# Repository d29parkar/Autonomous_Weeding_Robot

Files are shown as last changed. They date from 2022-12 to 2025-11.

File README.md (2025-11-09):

# Autonomous Weeding Robot

Weed control has been a long-standing issue in agriculture for over a century. The uniform spraying of herbicides has proved its efficiency in weed control, but it has also introduced environmental pollution, human health concerns, and herbicide resistance fears. Precision farming offers a solution to this problem by utilising weeding mechanisms to address individual plants or small weed clusters. Human-oriented precision weeding machinery, on the other hand, typically necessitates inefficient and labor-intensive human resources, which cannot justify the economic benefits of herbicide savings.

Therefore, with this project, we have presented the design, implementation and evaluation of a compact automated weed killing robot suited to traverse in marshy and moisture laden terrains, primarily cotton fields to uproot weeds which hinder growth of young cotton saplings.

The detailed report of the project is uploaded as "Project_report.pdf" in this repository.

The overall assembly of the the robot is uploaded in "CAD Models" repo as "assem1.SLDASM".

YOLO training data can be found here: [https://drive.google.com/drive/folders/1Qf1GGHQwgh6P5UD7bk6u21AzLAdbdTXJ?usp=sharing](url)
For ResNet Classification, data can be found here:
1. cotton: [https://drive.google.com/drive/folders/1kP8_Ejd9JK92aSImmd4kubfLfrTA65FS?usp=sharing](url)
2. weed: [https://drive.google.com/drive/folders/1wpcOpKExrO4X1uj2nVnzhOBSJXpHlJ4F?usp=sharing](url)

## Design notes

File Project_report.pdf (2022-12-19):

## Design & Development of Solar Assisted Autonomous Weed

## Killing Robot

## A DISSERTATION

### Submitted in partial fulfilment of the

### Requirements for the award of the degree

of

### BACHELOR OF TECHNOLOGY

in

### MECHANICAL ENGINEERING

By

Dhiraj Kiran Pimparkar (2019UME0199)

Nishtha Gupta (2019UME0180)

Shivank Kapila (2019UME0201)

Vansh Rai Saini (2019UME0200)

DEPARTMENT OF MECHANICAL ENGINEERING

INDIAN INSTITUTE OF TECHNOLOGY, JAMMU

Jagti, NH-44, Jammu - 181221, J&K, India. (Dec. 2022).

CANDIDATE’S DECLARATION

We hereby declare that the work presented in this dissertation entitled “Design & Development

of Solar Assisted Autonomous Weed Killing Robot”, submitted in partial fulfillment of the

requirements for the award of the degree of Bachelor of Technology in Mechanical Engineering

is an authentic record of work done by my/our own efforts with suitable acknowledgement to all

references.

This work has been carried out by us under the supervision of Dr. Roshan Udaram Patil,

Department of Mechanical Engineering, IIT Jammu during August 2022 to December 2022. We

have not submitted the matter embodied in this report for the award of any other degree or diploma

to any other institute or university.

Date: 10/12/2022

Place: Indian Institute of Technology Jammu

Dhiraj Kiran Pimparkar

Nishtha Gupta

Shivank Kapila

Vansh Rai Saini

CERTIFICATE

This is to certify that the above statement made by the candidate is true, to the best of our knowledge

and belief.

Dr. Roshan Udaram Patil

(Signature)

Mechanical Engineering, IIT Jammu.

## ACKNOWLEDGEMENT

We would like to express our sincere thanks, immense pleasure and gratitude to Dr. Roshan

Udaram Patil for his guidance & supervision throughout the entirety of this project. We would also

like to extend our gratitude towards the Evaluation Committee for their valuable inputs which help

shape the final product.

We are very thankful to our parents & all of our friends for their never-ending encouragement

in bringing out this dissertation report to the form as it is now.

Date : 10/12/2022

Place: Indian Institute of Technology Jammu

Dhiraj Kiran Pimparkar

Nishtha Gupta

Shivank Kapila

Vansh Rai Saini

## ABSTRACT

Research and development of autonomous mobile robotic solutions that can perform several active

agricultural tasks like sowing, harvesting, pruning etc. have been growing. Robots are now used

for a variety of tasks such as planting, weed killing, harvesting, and others. For performing these

tasks, detection of plants and weeds plays a vital role.

In this dissertation, we have developed a Solar Assisted Weed Killing Robot which is designed to

detect weeds (up to 12 cm in height) in a cotton field and remove them. Since different soils have

different water holding capacities, the design considerations for the robot have been estimated in

such a way so as to successfully traverse in marshy terrains of black cotton soil.

In the experimental section, a Raspberry Pi 4B and an Arduino Uno have been employed to garner

control of the custom 3-D printed wheels with spikes, rotor blade and an external camera for video

input feed. A Computer-Vision model using ResNet 50 architecture has been deployed on

Raspberry Pi, which is tasked with detecting and identifying if a cotton plant is present in front of

the robot or not via the video feed. The output from the computer vision model dictates the traversal

and commands the robot by prompting it to move forward, and take turns. The weed uprooting

mechanism is also characterized by the prompt received from the model to lower the rotatory blade

to perform the action of weed removal.

The present endeavor encompasses successful building of a prototype with all the mechanisms in

optimal working condition along with successful segregation of cotton and weed plants.

## CONTENTS

Certificate | 2
Acknowledgement | 3
Abstract | 4
Contents | 5
Nomenclature | 6
List of Figures | 7
List of Tables | 8

### 1 CHAPTER 1

1.1 INTRODUCTION | 9
1.2 LITERATURE REVIEW | 10
1.3 PROBLEM STATEMENT | 12
1.4 OBJECTIVES | 13

### 2 CHAPTER 2

2.1 DATASET & WORKING AREA MATRIX | 15
2.2 ROBOT MODEL & ASSEMBLY | 17
2.3 CALCULATIONS | 19
2.4 WORK STRATEGY | 21

2.4.1 Robot Path Traversal

2.4.2 Plant Identification & Detection

2.4.3 Weed Uprooting Mechanism

2.5 CIRCUIT DIAGRAMS & SPECIFICATIONS | 24

### 3 CHAPTER 3

3.1 OBSERVATIONS | 27
3.2 RESULTS AND DISCUSSION | 29

### 4 CHAPTER 4

4.1 CONCLUSIONS | 31
4.2 FUTURE SCOPE OF WORK | 33
REFERENCES | 34
APPENDIX | 35

## Nomenclature

RR | Rolling Resistance acting on the Robot
AR | Aerodynamic Resistance acting on the Robot
GR | Grade Resistance acting on the Robot
Ρ | Density of air
A | Frontal Area of the Robot
V | Velocity of the Robot
Cd | Coefficient of Drag
α | Angle of slope

## List of Figures

Chapter 1

1.2.1 Multilayer Design Framework for Intelligent Agricultural Machines & Field Robots 10

1.3.1 Line Sowed Cotton Fields | 12
1.3.2 Weeds Present in the Field | 12
1.4.1 Field Working Area in Jammu | 14

Chapter 2

2.1.1 Theoretical Grid Arrangement of Cotton | 15
2.1.2 Actual Grid Obtained in Field | 15
2.1.3 Images Captured from Field to Create Dataset | 16
2.2.1 CAD Model of Robot Assembly | 17
2.2.2 Side View of Robot Asembly | 17
2.4.1 Workflow of Path Traversal Algorithm | 21
2.4.2 Workflow of CV Model | 22
2.4.3 Workflow in Case of Weed Detection | 23
2.5.1 Hardware Connection b/w Raspberry Pi & Arduino | 24
2.5.2 Circuit for Variable Speed Control | 25
2.5.3 L298 & Arduino Powered Separately | 25
2.5.4 Hardware Connection for Linear Actuator | 26

Chapter 3

3.1.1 Output from Computer Vision Model | 27
3.1.2 3-D Printed Wheels & Robot Casing | 28
3.2.1 Wheel Assembly | 29
3.2.2 Performance of Computer Vision Model | 30

## List of Tables

Chapter 1

1.4.1 Specifications for Project Objectives | 13

Chapter 2

2.2.1 List of Components of Robot Assembly | 18
2.3.1 Design Considerations & Parametric Values Assumed | 19

Chapter 11

3.2.1 Parameters for FDM | 29

## 1.1 INTRODUCTION

Weed control has been a long-standing issue in agriculture for over a century. The uniform

spraying of herbicides has proved its efficiency in weed control, but it has also introduced

environmental pollution, human health concerns, and herbicide resistance fears. Because of the

negative consequences, governments and farmers are attempting to limit herbicide use in

agricultural activity. Precision farming offers a solution to this problem by utilising weeding

mechanisms to address individual plants or small weed clusters. Human-oriented precision

weeding machinery, on the other hand, typically necessitates inefficient and labor-intensive human

resources, which cannot justify the economic benefits of herbicide savings.

Because of its considerable potential to improve weeding efficiency while lowering environmental

and economic costs, automated weed control, including weed detection and removal, has acquired

substantial popularity in the precision farming community in recent years. Many robotic weed

control systems have been proposed, with a focus on single tactics such as selective chemical

spraying, mechanical weeding, flaming, and electrical discharge. To detect weeds, smart weeding

machines rely on the performance of the machine vision system. However, environmental

uncertainties such as illumination and colour variation in leaves or soil impair the performance of

the machine vision system, limiting the weed control accuracy. Significant progress has been made

toward learning-based weed detection technologies as artificial intelligence has flourished. Such

systems, which employ a Convolutional Neural Network (CNN), have been shown to produce

more reliable crop/weed detection findings.

Within the scope of our project, we have presented the design, implementation and evaluation of

a compact automated weed killing robot suited to traverse in marshy and moisture laden terrains,

primarily cotton fields to uproot weeds which hinder growth of young cotton saplings. Cotton was

chosen as part of the study as it constitutes a majority chunk of the agricultural economy and as of

now, is extremely expensive due its labour-intensive nature of weed uprooting in thick black soil.

By targeting this niche and automating it, we aim to innovate a sustainable solution for cotton

farming industry.

## 1.2 LITERATURE REVIEW

After conducting a detailed literature survey to understand the developmentds made in this domain

we came across a multilayer design framework for intelligent machines and field robots consisting

of four technology layers. This can be depicted in Figure 1.2.1. They tend to stack on each other

beginning from the machine architecture layer containing both the hardware and software

architecture required for the robot’s functioning. Next comes the machine awareness layer

consisting of the perception localization, and monitoring technology required by the robot to be

aware of its own systems and environment.

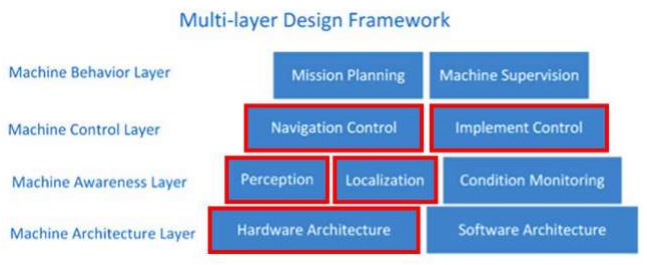
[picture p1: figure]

Figure 1.2.1: Multilayer design framework for intelligent agricultural machines & field robots

Robots interact with their surroundings, necessitating the inclusion of actuator control systems in

the machine control layer. Machine planning and supervision technologies connected with the top

machine behaviour layer are essential for autonomy and the ability to achieve goals under

uncertainty. According to a review of the literature, robotic weeder technologies have typically

included technology at the lower three layers such as hardware architecture, perception,

localization and navigation, and implement control. The machine behaviour layer, as well as

condition monitoring technology, are mainly lacking. As a result, it is impossible to conclude,

without diminishing the technological effort published in the literature, that we have robotic

weeding technology today. However, developments in the field are accelerating.

All the robotic weeders documented in the literature are not truly robotic weeders, but are

‘essentially self-guiding vehicles carrying weeding tools.’ It is based on the fact that the practical

application of mechanical weeding instruments is complicated. This complexity is due to various

aspects, including soil qualities that change depending on soil type and environmental conditions

such as soil moisture content, variability in weed plants and crop plants, and the reaction of these

plants to mechanical weeding instruments.

Several key factors must be met for agricultural robots to effectively control weeds. Problems must

be resolved. First, weed and crop plants need to be accurately spotted in a field of crops. Plant

location, classification of weed and crop plants, and plant detection must all be part of the

perceptual system. Second, the weed control strategies that best suit the cultural norms of the

production system must be considered while developing the weed control mechanisms. Third, the

mechanism must be directed to function near the locations of the weed plants and far from the crop

plants depending on the data from the perception system. Fourth, a weeding system must

incorporate each of these technologies. We focused on developing of a robotic weeder including a

perception system and path traversal algortihm specifically targeted around cotton plants. The

adaptability of the system still stands with the flexibility factor primarily dependent upon the

dataset proivded for training and validation purposes. However, the design is precisely designed

to operate in fields where line-sowing is a common practice.

## 1.3 PROBLEM STATEMENT

The Indian economy is largely agro-based as agriculture constitutes the backbone of the rural

livelihood security system. With more than 100 million farm holdings, agriculture supports more

than 60 % of the total population in India and contributes about 19% to India’s GDP. With cotton

at the forefront, it contributes about 16% of the total agricultural-crop of the country with India

possessing the largest area under cotton cultivation which is nearly 9 million hectares. Therefore,

it becomes increasingly crucial to ensure a good annual harvest as it holds a significant chunk in

the exports in the Indian economy. Each year, massive capital investments are required in terms

of manpower as extensive care is required by the line sowed cotton plants during their early

development stages. Any obstruction such as weeds can significantly affect and hinder their

growth. Additionally, while operating here, the moisture retentive black soil poses difficulty to

work in due to its extremely marshy nature. This makes the task of weeding very difficult and

labour intensive. Hence, it becomes necessary to incorporate automation in this sector and provide

a sustainable solution to address this grave issue and ensure good yield of cotton plants by

uprooting weeds in a more economical fashion. Refer Figure 3.1 & 3.2 for cotton fields and weed

presence in fields.

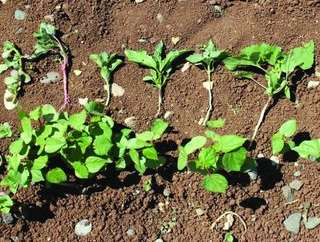
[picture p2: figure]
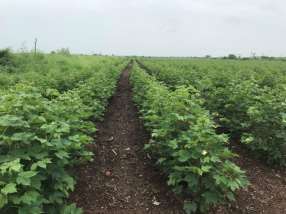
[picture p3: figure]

Figure 1.3.1: Line Sowed Cotton Fields | Figure 1.3.2: Weeds Present in the Field

## 1.4 OBJECTIVES

- Designing & developing a robot capable of traversing in marshy terrains.
- Developing a computer vision model to facilitate cotton plant identification.
- Developing a path planning and mapping algorithm for autonomous maneuvering of

the robot in alien terrains.

- Developing a weed uprooting mechanism to uproot weeds up to 12 cm in height.

The primary objective of this project is to develop a solar power assisted autonomous weed killing

robot. The robot specifications should be such that it can traverse in marshy black soil while

avoiding sinkage and move freely amongst the cotton grids. The agenda of developing this robot

caters to uprooting weed around young cotton plants to prevent hampering their growth. The

problem scope and objectives that are dealt with as part of this research project are as follows in

Table 1.4.1:

Problem Scope to be Dealt With | Specification
Field Size (Working Area) | 25 x 30 sq. ft
Soil Density | 1.81 - 2.08 g/cm^3
Operation Time | 30-35 mins
Weight | Under 10 Kgs
Operational Stage | Budding cotton plants (H= 2-3 ft)
Grid Size for Each Plant | 20 cm x 20 cm

Table 1.4.1: Specifications for Project Objectives

For the purpose of this project a field was planted with cotton seeds to serve as our working area

and facilitate manual curation of dataset to suit our requirements. Refer to Figure 1.4.1 for the field

working area in Jammu.

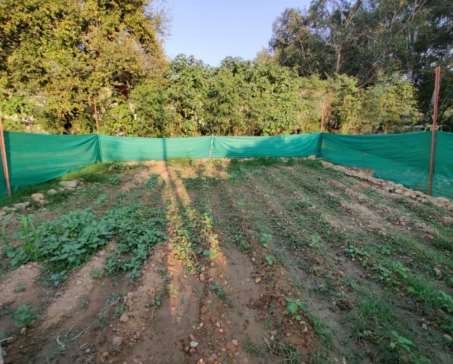
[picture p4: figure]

Figure 1.4.1: Field Working Area in Jammu

## 2.1 DATASET & WORKING AREA MATRIX

Cultivating our own cotton field sowed in matrices was crucial for the development of the project

to procure data and understand the practical obstructions the robot might face while maneuvering

autonomously. It yielded reliable data spread across weeks to record all stages of plant growth for

long-term considerations. Figure 2.1.1 & 2.1.2 demonstrate the theoretical and actual grid size and

matrix obtained with line sowed cotton.

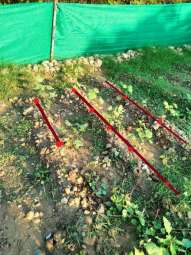
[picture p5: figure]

Figure 2.1.1: Theoretical Grid Arrangement of Cotton | Figure 2.1.2: Actual Grid Obtained in Field

To suit the requirements of our robot and train it precisely instead of availing the dataset available

on the internet, we manually curated our own dataset and video footage to handle real-life

situations in a more concrete way and make our model robust. While procuring the images,

extensive care was given to collect the photographs at a specified height and angle of 18 inches

and 30 degrees from the vertical respectively. This was ensured in order to accurately replicate the

point of view of the camera module on the robot and hence obtain better results. Some images can

be seen in Figure 2.1.3 which demonstrate the various situations our robot might encounter itself in: plain terrain, rocky terrain, marshy terrain and area with a thick growth of weed. To access the

full dataset, refer to the appendix.

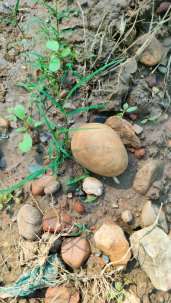
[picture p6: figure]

Fig. 2.1.3.1 | Fig. 2.1.3.2

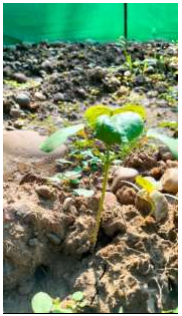
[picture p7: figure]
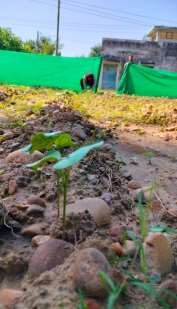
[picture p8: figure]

Fig 2.1.3.3 | Fig. 1.5.3.4

Figure 2.1.3: Images Captured from Field to Create Dataset

## 2.2 ROBOT MODEL & ASSEMBLY

With the specifications laid out the designing considerations were obtained to aid in the

development of the CAD model of the robot. Refer to Figure 2.2.1 & 2.2.2 for the assembly.

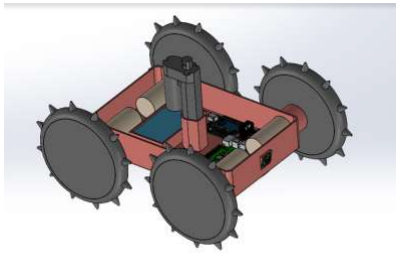
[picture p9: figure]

Figure 2.2.1: CAD Model of Robot Assembly

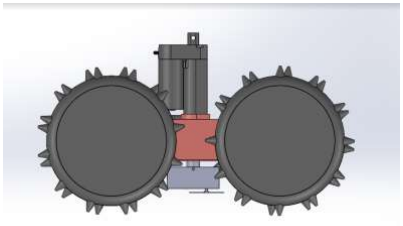
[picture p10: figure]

Figure 2.2.2: Side View of Robot Assembly

The list of components incorporated in this assembly are as follows as found in Table 2.2.1:

Component | Quantity
Wheels | 4
Actuator Stroke | 1
Linear Actuator | 1
Arduino Uno | 1
Battery | 1
Fan Blade | 1
Body Casing | 1
Raspberry Pi 4B with Camera Module | 1
Connector Rod | 1
Motors | 5

Table 2.2.1: List of Components in Robot Assembly

Refer to the appendix for the drawings of all the components in the assembly.

## 2.3 CALCULATIONS

The assumptions and design considerations taken into account while performing the calculations

have been listed below in Table 2.3.1

Design Consideration | Value
Weight of the Robot | 100 N
Wheel Radius | 0.08 m
Efficiency of Transmission (%) | 90
Coefficient of Friction | 0.65
Coefficient of Rolling Resistance | 0.15
Target Gradability (%) | 50
Target Velocity (m/min) | 10
Frontal Area of Robot (m² ) | 0.02
Density of air (kg/m³ ) | 1.225

Table 2.3.1: Design Considerations & Parametric Values Assumed

For deciding the required specifications of the motor, we’ll estimate all the loads acting on the

robot.

Total LoadRobot = RR + AR + GR

RR estimation:

RRRobot = μ * WeightRobot

RRRobot = 0.15 * 100 = 15 N

AR estimation:
ARRobot = ½ *ρ*A*V²
*Cd
ARRobot = ½ * 1.225 * 0.02 * (10/60)² * 1

ARRobot = 0.003 N

GR Estimation:

GRRobot = Weight * sin(α)

GRRobot = 100 * sin (26.56°) = 44.72 N

Total LoadRobot = RRRobot + ARRobot + GRRobot

= 15 + 44.72

= 59.72 N

Torque Required on Wheels (Tw) = Total LoadRobot * RadiusWheel

= 59.72 * 0.08

= 4.77 N-m

Torque to be Supplied by Motor (TM) = TW/ (Efficiency*Gear Ratio)

= 4.77/ (0.9*1)

= 5.3 N-m

Torque Supply per Motor = TM/Number of Motors

= 5.3 / 4

= 1.325 N-m

## 2.4 WORK STRATEGY

### 2.4.1 Robot Path Traversal

The robot path traversal algorithm traces out & maps the path to be travelled by the robot. The

algorithm deployed for the same is A* search algorithm which is a graph traversal and path search

algorithm. The heuristics incorporated here define how the robot

Heuristic = w (Manhattan Dis. to Goal State) + (1-w) ( Perpendicular Dis. to S1-G1 Line)

The flowchart for the working of the path traversal algorithm can be seen in Figure 2.4.1

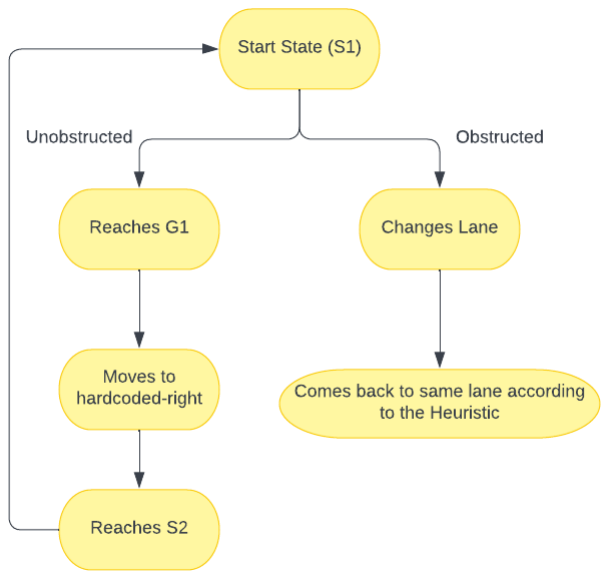
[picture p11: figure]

Figure 2.4.1: Working of Path Traversal Algorithm

### 2.4.2 Plant Identification & Detection

The computer vision model employs ResNet architecture as its image processing algorithm. The

external camera module which dangles in the absolute front of the robot vehicle has been placed

in such a way so as to avoid any overlooking of weeds. The camera module captures and inputs

video feed to the computer vision model at an interval of 10 frames for processing and the output

identifies and labels the plant as ‘Cotton’ or ‘Not Cotton’. Thus, if a weed is identified the response

for triggering the weed uprooting mechanism is set into motion. Figure 2.4.2 displays the

algorithmic flowchart of how it operates.

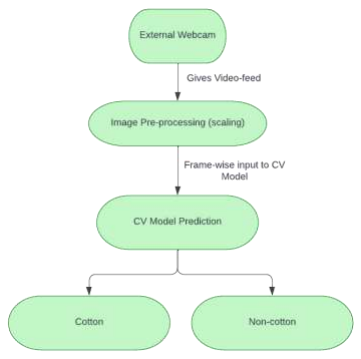
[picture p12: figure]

Figure 2.4.2: Workflow of CV Model

### 2.4.3 Weed Uprooting Mechanism

The weed uprooting mechanism that has been integrated with the system includes a motor blade

which is lowered via a linear actuator of maximum stroke length of 100 mm. In case the computer

vision model detects any weed, the robot is immediately brought to rest and the mechanism is set

into motion. The Raspberry Pi relays the signal to L298 via Arduino Uno while simultaneously

triggering the linear actuator. The pictographic representation has been depicted in Figure 2.4.3

which can be found below.

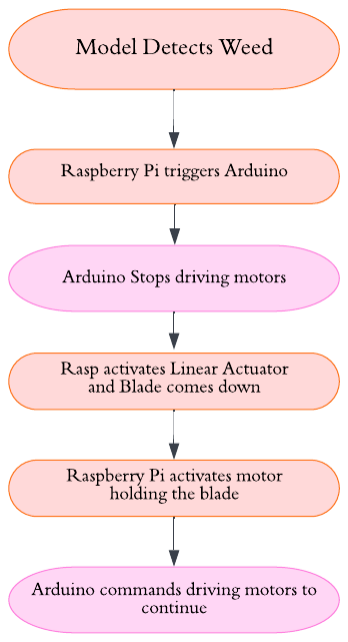
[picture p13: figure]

Figure 2.4.3: Workflow in Case of Weed Detection

## 2.5 CIRCUIT DIAGRAMS & SPECIFICATIONS

The circuit diagrams are crucial in representing the essence of the working of the robot. Various

mechanisms operate in unison to optimally function the robot in its task of uprooting weeds while

deployed in the working area. Three primary circuits have been integrated to perform and set

communication which include:

Raspberry Pi – Arduino Uno Communication

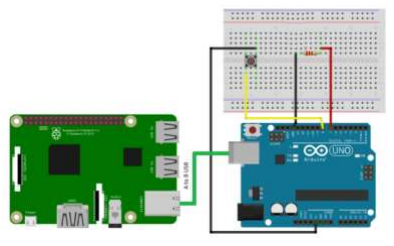
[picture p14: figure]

Figure 2.5.1: Hardware Connection b/w Raspberry Pi & Arduino

Figure 2.5.1 depicts the hardware connection between Raspberry Pi & Arduino Uno. It has an

added camera module which provides the input to the processing unit and is evaluated by the

Computer Vision Model. The command is further relayed via Arduino to perform the necessary

action. The specifications of the components are listed below:

- Raspberry Pi 4 Model B; 4 GB, ARM-Cortex-A72 4 x, 1.50 GHz, 4 GB RAM, WLAN-ac,

Bluetooth 5, LAN, 4 x USB, 2 x Micro-HDMI

- Breadboard with 400 Tie Points (BB-801)
- Arduino Uno R3 ATmega328P with USB Cable

Arduino Uno – Motor Driver – Motor Communication

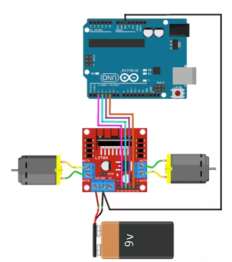
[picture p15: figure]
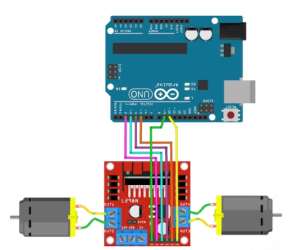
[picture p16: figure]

Figure 2.5.2: Circuit for Variable Speed Control Figure 2.5.3: L298 & Arduino Powered Separately

Figure 2.5.2 & 2.5.3 denote the hardware connection for variable speed control of motors and the

power supply of the circuit respectively. The Raspberry Pi relays commands to the Arduino to

control the motors and the robot and a power supply of 12V is being provided. The specifications

of the components are as follows:

- Orange Planetary Gear DC Motor 12V 92RPM 234.7 N-cm PGM45775-50.9K
- Motor Driver L298 dual H-bridge driver chip.
- Panasonic Li-Ion 2000mAh type, 1900mAh min, pre-charged rechargeable AA batteries.
- 8 CELL 1.5v AA Battery Case Holder, Battery Holder Box with Cover ON/Off Switch

Arduino Uno – 2 Channel Relay – Linear Actuator Communication

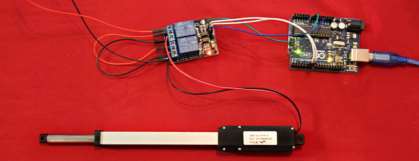
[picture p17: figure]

Figure 2.5.4: Hardware Connection for Linear Actuator

Figure 2.5.4 represents the hardware connection between the processing unit, to a 2-channel relay

which further activates the linear actuator. This connection is triggered by the computer vision

model when it detects any nearby weed. The linear actuator gently lowers the piston to

consequently lower the blade for any removal of weeds detected. The specifications of the

components used for this circuit include:

- Linear Actuator Stroke Length 100MM,7mm/S,1500N,12V
- 5V 10A 2 Channel Relay Module Shield for Arduino ARM PIC AVR DSP Electronic

## 3.1 OBSERVATIONS

When the robot was deployed in the field it was observed that with the non-conventional wheel

designs that have been used in the robot with the spikes, we were able to successfully maneuver

in the marshy terrain. The robot did not wobble much and remain stabilized while traversing. The

rocky terrain was within the scope of expectations leading to enhance the motor design

considerations. However, the speed output expected was slightly lower relative to the theoretical

value.

When the camera was tested in the field to ensure high performance of the computer vision model,

the following results were obtained as seen in Figure 3.1.1:

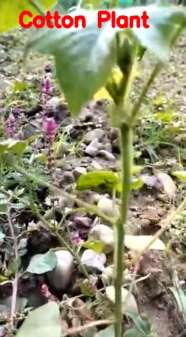
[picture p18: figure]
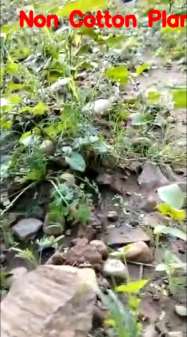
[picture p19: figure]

Figure 3.1.1: Output from Computer Vision Model

The traversal of the robot from the start state to the goal state with continuous updating for each

grid was successful with the robot completing this distance without waving off its path. Therefore,

it was observed that integration of A* search algorithm for path planning was a success.

For removal of weed the mechanism in place we aim to be able to cut it down to its stem, with the

remains still present near the main plant body. It was safe to conclude that the robot is capable of

doing this task while testing the circuit of linear actuator separately from the body.

As for the components, the 3D printed parts include customized wheels and the robot body as

observed in Figure 3.1.2. The printed casing was observed to be a little deviated from the CAD

model due to some errors in the FDM 3-D printer.

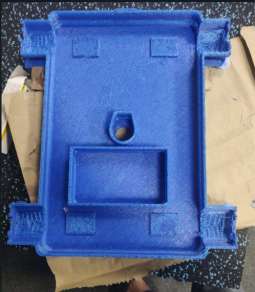
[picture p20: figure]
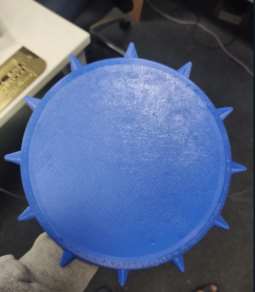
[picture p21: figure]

Figure 3.1.2: 3-D Printed Wheels and Robot Casing

## 3.2 RESULTS & DISCUSSION

The wheel was successfully manufactured using the FDM 3D printer available in the tinkering

lab. The material was chosen to be Polylactic Acid. Table 3.2.1 shows the parameters for 3-D

printing.

Table 3.2.1: Parameters for FDM

S. No. | Parameter | Value
1 | Infill Density | 20%
2 | Infill pattern | Triangle
3 | Printing Temperature | 210 ℃
4 | Build Plate Temperature | 60 ℃
5 | Printing Speed | 50 mm/s
6 | Top Thickness | 0.3 mm
7 | Bottom Thickness | 0.6 mm

The base was not successfully printed due to some technical problem in the nozzle. The parameters

were chosen to be the same as that of the wheel. We observed an abundance of pores in the base

which significantly reduced its strength.

Figure 3.2.1: Wheel Assembly

Figure 3.2.1 shows the wheel assembly. The keyway was purposely designed to be of a tight fit to

prevent slipping. This resulted in a great torque transfer from the motor to the wheels.

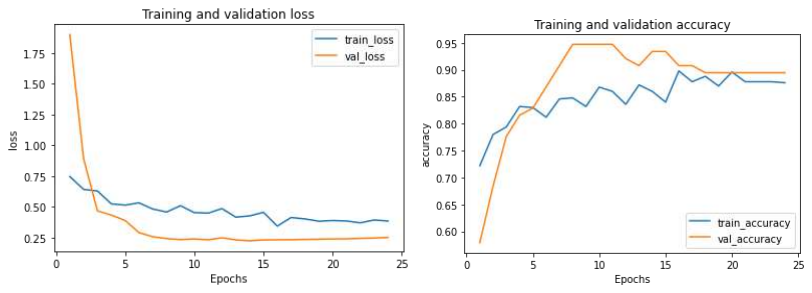
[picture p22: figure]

Figure 3.2.2: Performance of Computer Vision Model

Using the site-collected dataset, we trained a computer vision model to recognise cotton plants. Its

accuracy in both training and validation was 90.1% and 89%, respectively. The plot shown above

in Figure 3.2.2 displays how the accuracy and loss vary with training epochs. We can observe that,

while converging without overfitting, our validation loss is less than our training loss. Furthermore,

it is implied by the plot, it is neither exploding or becoming stranded.

## 4.1 CONCLUSION

This work proposed the development of a weed uprooting robot with current state-of-the-art

localization and mapping techniques along with a well-equipped computer vision model to identify

and differentiate between cotton and weed. After an intensive research and development phase

spanning over 12 weeks we were able to develop a working prototype characterized and trained

by the dataset which was manually curated to specifically suit the needs of the robot. The scope of

this project focuses on the early developmental stages of young cotton plants with a height of about

25 inches. After developing a deeper product sense, segregating the current targets from future

goals was facilitated with the research to enhance the prototype extending to the next semester.

Since there were about four major considerations in this robot the following could be mapped out

for the domains:

Robot Design:

The robot body was deliberately made small for efficient maneuvering in between the narrow

channels. With proportionately larger wheels attached at a small angle, a degree of stability was

imparted to the model to avoid any toppling. A protruding camera in front of the robot relays the

visual input to Raspberry Pi model so that the robot does not miss or cross any potential weeds

along the way.

Cotton Identification Model:

It is safe to conclude that by employing the ResNet Architecture with a dataset of over 800 images,

an accuracy of 89% was achieved. The computer vision model was successful in identifying the

plants even in a destabilized self-captured video input. Further enhancements in the model have a

direct positive correlation with the increasing number of epochs and quality data.

Traversal & Path Planning Algorithm:

The A* traversal algorithm employed in the robot includes simple linear motion with a restricted

degree of freedom of movement to avoid wandering away from the established grid structure.

When it reaches the end of a channel, it takes a 90 + 90 degree turn towards the right following

the channel yet again. The requirement of 3D localization in agriculture is quite rare with research

still premature. The integration of localization & mapping algorithm with the model is still

underway with a tremendous potential to grow.

Weed Uprooting Mechanism:

The current weed uprooting mechanism employs a rotatory blade and a linear actuator which is

gradually lowered in case of presence of weed. The output from the motor is successfully converted

by the actuator and the blade cuts down the weed from surface level. A deeper uprooting of weed

takes place in soil areas with a soft texture which can be penetrated by the blade with ease and

without suffering any damage.

## 4.2 FUTURE SCOPE OF WORK

The autonomous weed killing robot developed yielded exciting results but also revealed pathways

for improvement and future scope of work. Some problems that were faced during the fabrication

phase of the robot need further diving into for either enhancement or troubleshooting. There

remains much scope to improve the accuracy of the computer vision model by deploying latest

algorithms and harboring access to ‘Agastya’ supercomputer to accelerate model training and

validation.

Implementation of path planning and traversal algorithms for localization and mapping of alien

territories requires expertise in SLAM, an algorithm which is still premature in context to

agriculture and forestry. By modifying the design of the model to accommodate more cameras, we

may be able to reduce the engagement of a single camera for multiple visual tasks. By enhancing

the power supply and establishing a solar-powered recharging station to ensure constant power

availability we may procure video feeds from multiple perspectives for training an end-to-end

model for weed-crop identification and detection. Regular monitoring by the robot and relaying

the feed to a database, a library of weed and cotton plant images can be curated to bolster the

research of crop-weed differentiation.

References

1. Wu, Xiaolong & Aravecchia, Stéphanie & Lottes, Philipp & Stachniss, Cyrill & Pradalier,

Cedric. (2020). Robotic weed control using automated weed and crop classification.

Journal of Field Robotics. 37. 10.1002/rob.21938.

2. Averill, K.M. et al. (2022) “Effects of Tertill® weeding robot on weed abundance and
diversity,” | Agronomy, | 12(8), | p. | 1754. | Available | at:

https://doi.org/10.3390/agronomy12081754.

3. Du, Y. et al. (2021) “A low-cost robot with autonomous recharge and navigation for weed

control in fields with narrow row spacing,” 2021 IEEE/RSJ International Conference on

Intelligent | Robots | and | Systems | (IROS) | [Preprint]. | Available | at:

https://doi.org/10.1109/iros51168.2021.9636267.

4. Steward, B., Gai, J. and Tang, L. (2019) “The use of agricultural robots in Weed

Management and Control,” Robotics and automation for improving agriculture, pp. 161–

186. Available at: https://doi.org/10.19103/as.2019.0056.13.

Appendix

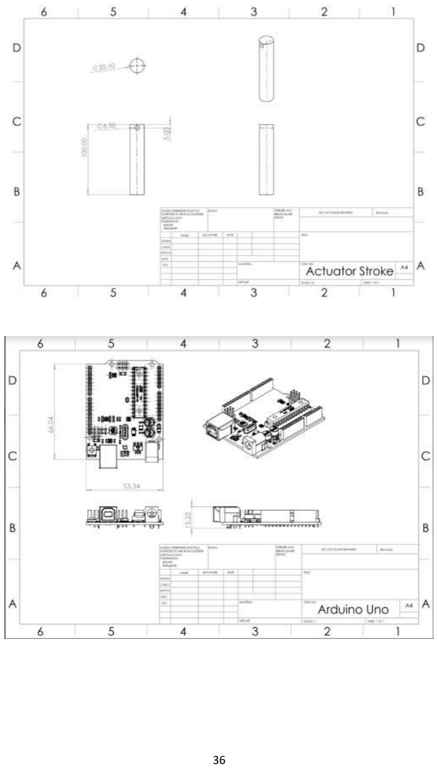
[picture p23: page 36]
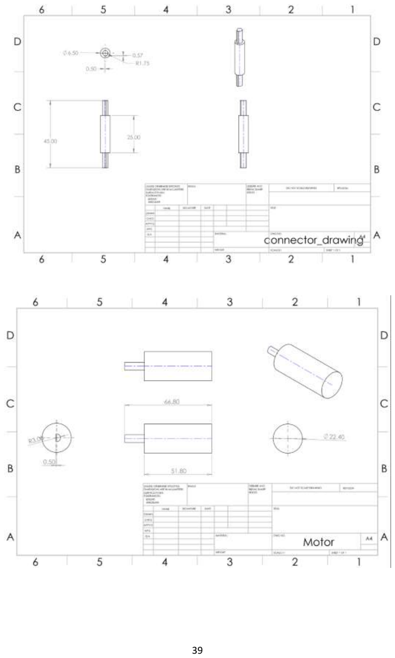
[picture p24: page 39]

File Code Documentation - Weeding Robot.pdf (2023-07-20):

After setting up the raspberry pi and setting up the ssh, follow the below-mentioned steps to run code for multiple tasks:

### 1. Motor with speed control:

File - motor_with_speed_control.py
All the motor and linear actuator-related tasks can be accomplished using this file. Verify that all the Raspberry Pi GPIO pins are connected to their respective motors and linear actuator.
You can use the following diagram as a reference:


The GPIO pin numbers will depend upon what GPIO.setmode(GPIO.BOARD) or GPIO.setmode(GPIO.BCM), as seen in the following image.
[In the image as well as by default in the code file: GPIO.BOARD mode is set]


Eight tasks can be accomplished using this Python file -
a. Forward
b. Reverse
c. Left_turn
d. Right_turn
e. Cutting
f. Stop_cutting
g. Actuate
h. Dactuate

We can progressively mention the task we want to accomplish in the while loop of the file, as can be seen in the image below:


Note:
You have to mention the time.sleep(x) [x being the number of seconds] after every task, as seen in the image.
Speed can be mentioned from range (0, 100), though, for speeds < 15, the robot might not move due to its inability to overcome static friction.

### 2. For all the tasks:

File: BTP_main.py [GitHub], BTP folder, file name: main.py (or similar) [Raspberry Pi memory card]

This file contains the entire code for the weeding operation apart from the path traversal. The code initially captures the webcam video with cv2.VideoCapture(0) command.

The object detection model identifies the weed and cotton plants based on their training and operates accordingly.

If the weed is found to be with > 0.5 confidence, the robot will start its cutting operation.
No code is written for the cotton plant to replan the robot's path based on its identification.

### 3. Computer Vision Model Scripts - Resnet:

File: CV_model.ipynb [Github] - very well-organized and easy-to-use Python notebook This file contains the entire code required for computer vision model training.
The file also contains code for testing the model on any video or webcam input based on the cv2.VideoCapture(0) command.
The data on which it is trained is attached with the google drive link below.

### 4. Object Detection Scripts - YOLOv7:

File: yolo_training.ipynb [Github]
This file contains the entire code required for YOLO model training.
The code for model testing is also mentioned in the Python notebook.

### 5. Path Traversal Scripts - A-star:

File: Astar_weed_killing_robot.ipynb
All the heuristics and conditions have already been implemented for the path traversal. [For more info about the heuristics, you can refer the BTP report file]
The only input required for the operation of the code is start_node and end_node. Call the run function from the initialized Robot class, giving it all the arguments.
The image displays the entire path that the algorithm has designed.


The object detection and path traversal files haven't been integrated fully into the motor operation codes, which can be a task of future developers. However, it has been attempted in a few files found in the raspberry pi memory card but hasn’t been tested.

For any information, contact: Vansh Rai Saini: +91 96544 58060 Dhiraj Pimparkar: +91 98501 92860 Nishtha Gupta: +91 94525 01659 Shivank Kapila: +91 97977 11244

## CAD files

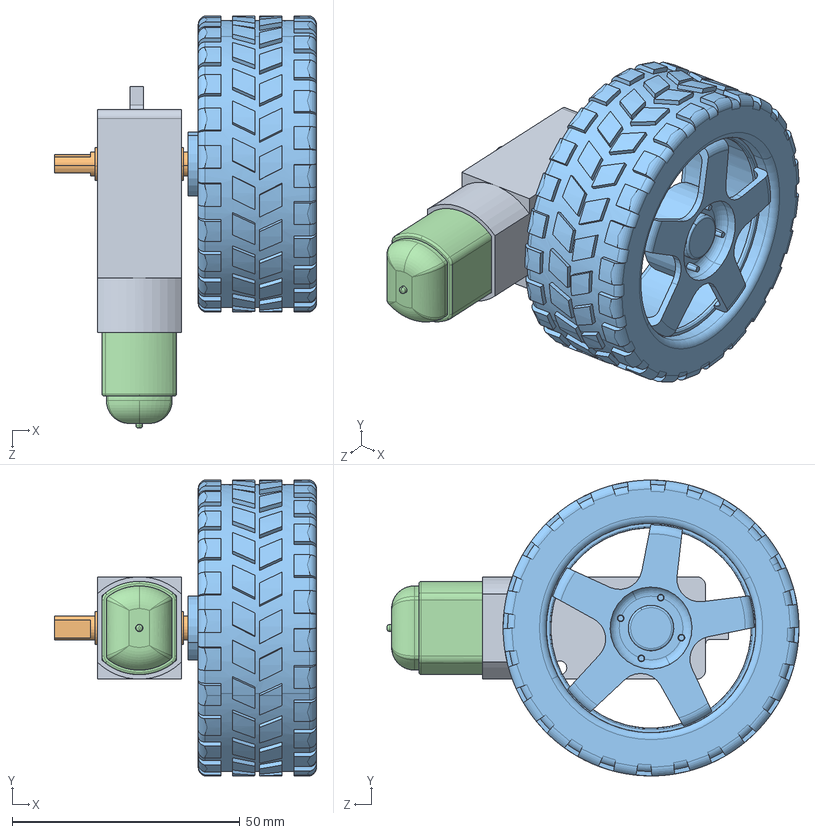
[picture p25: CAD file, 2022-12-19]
CAD Models/Bo Motor With Wheel.SLDASM
57.6 x 65.0 x 90.5 mm
Real Bo Motor Gear Box.STEP
Shaft.STEP
Real Wheel.STEP
Real Bo Motor Frame.STEP

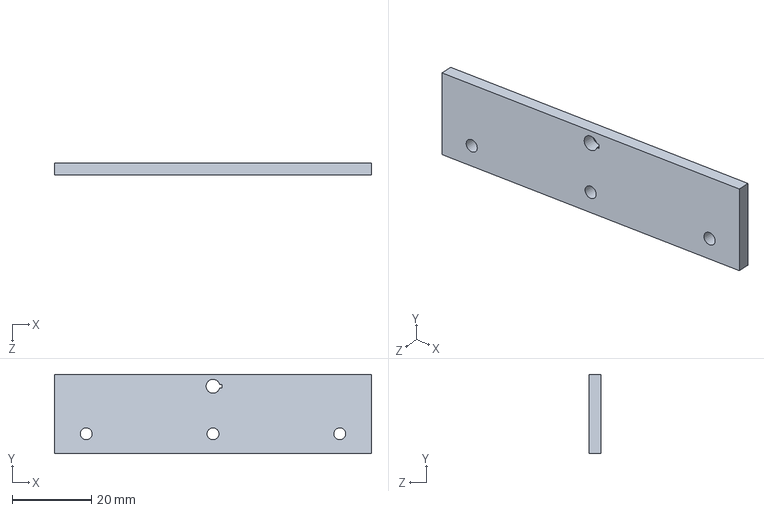
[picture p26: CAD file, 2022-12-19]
CAD Models/assembley component.SLDPRT
80.0 x 20.0 x 3.00 mm

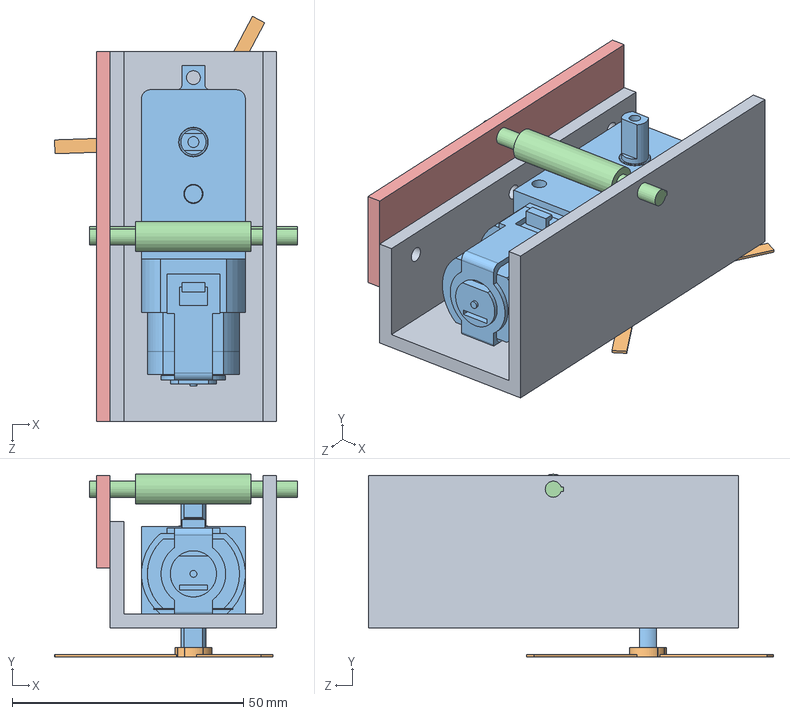
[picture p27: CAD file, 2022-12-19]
CAD Models/tool_assembly.SLDASM
52.5 x 39.5 x 87.7 mm
tool_casing
blade
BO DC Motor
connector
assembley component

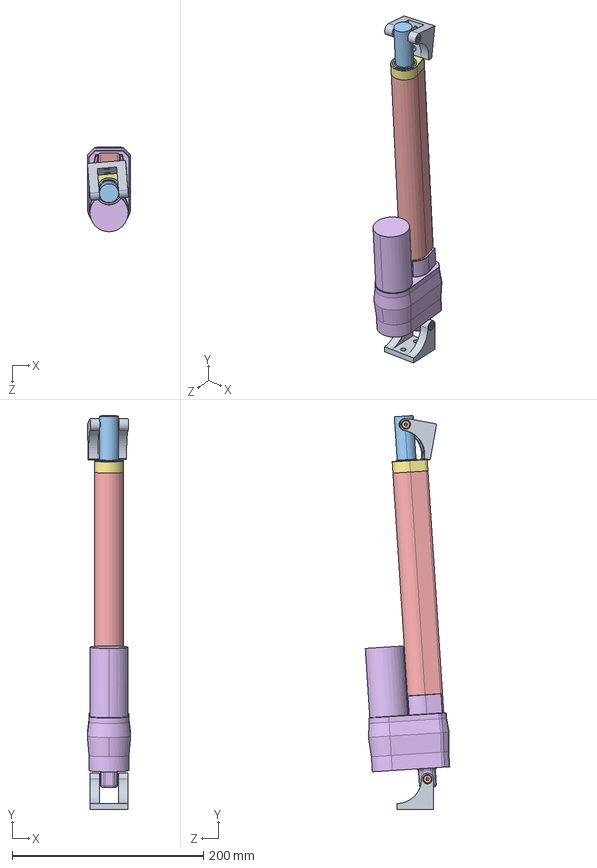
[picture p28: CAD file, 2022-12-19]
CAD Models/linear actuator.SLDASM
45.5 x 412.5 x 88.5 mm
HDA Clevis Mount.STEP x 2
Shoulder Bolt .25 x 1 - 10-24_SHSSCREW 0.25x1-N.STEP x 2
HDA-STROKE_8IN.STEP
HDA-CAP-SEAL.STEP
HDA-SHROUD_8IN.STEP
HDA-BASE.STEP
HDA-SHROUD-CAP.STEP

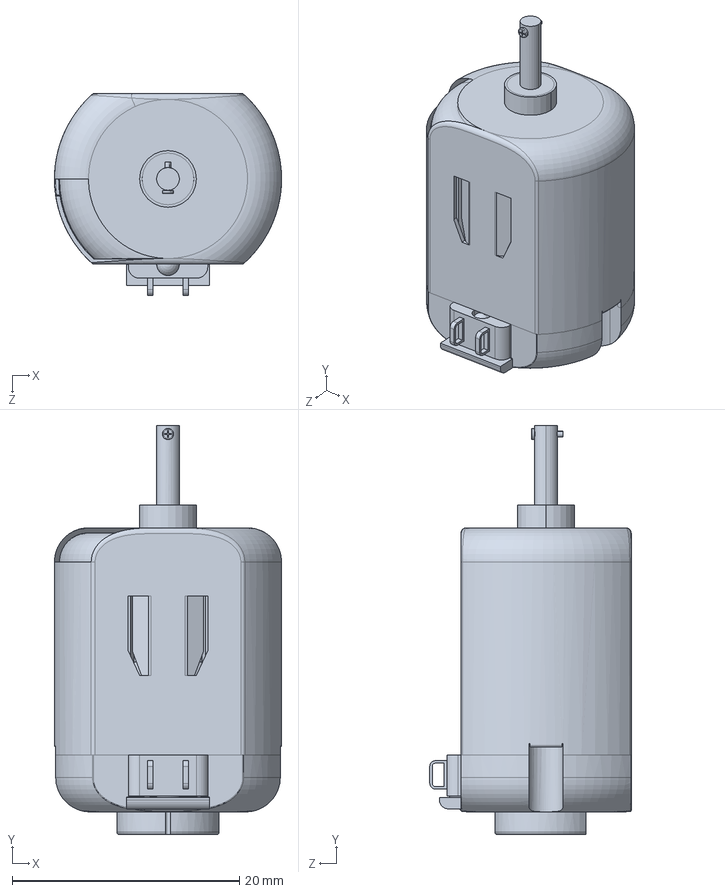
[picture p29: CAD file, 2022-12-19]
CAD Models/DC_Motor assembly.SLDPRT
20.0 x 36.0 x 17.7 mm

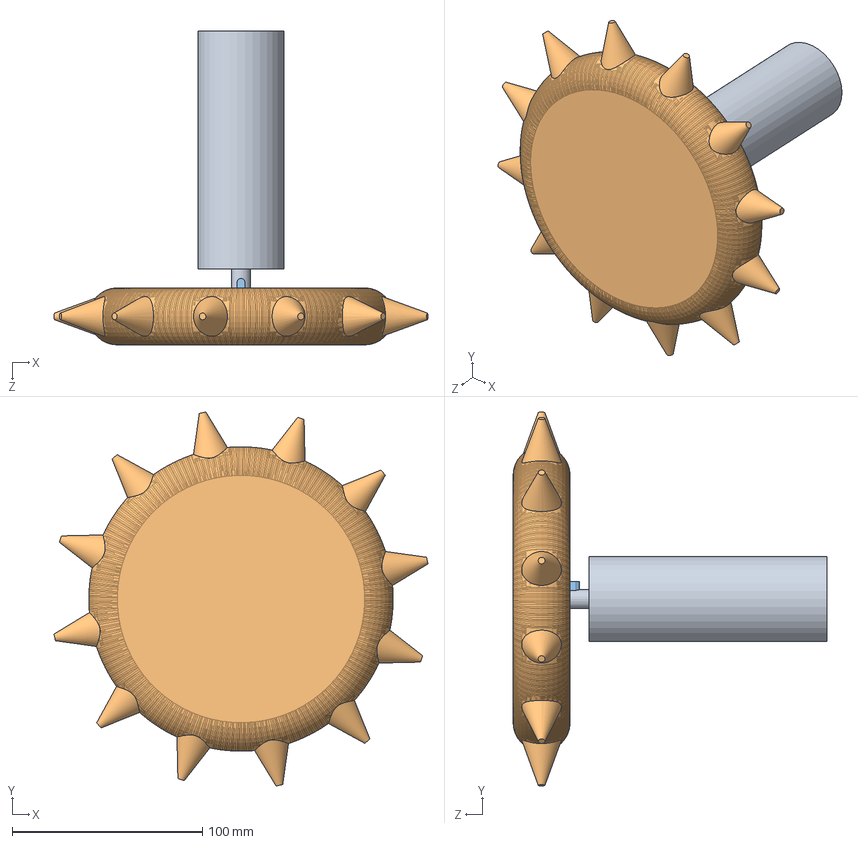
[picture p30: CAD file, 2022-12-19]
CAD Models/motor_wheel_sub_assemb.SLDASM
196.6 x 196.6 x 165.0 mm
motorV2
WheelV2
key

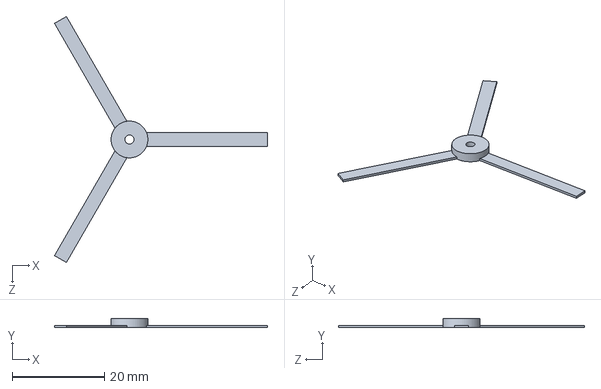
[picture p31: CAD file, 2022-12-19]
CAD Models/blade.SLDPRT
46.3 x 2.00 x 53.5 mm

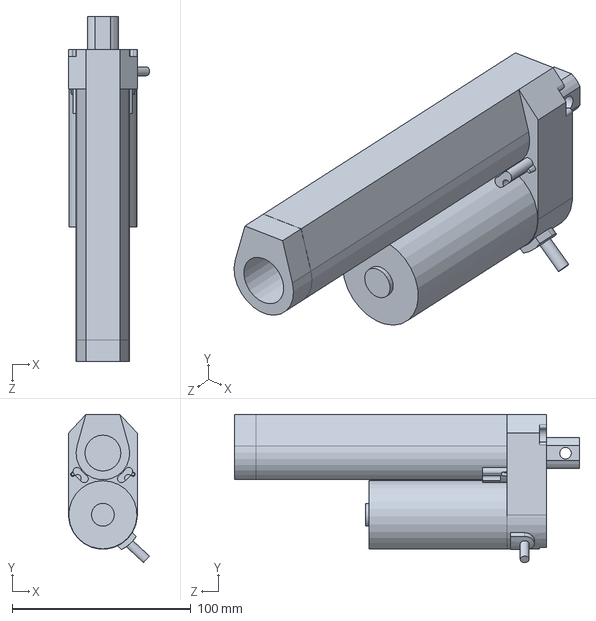
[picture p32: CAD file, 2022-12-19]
CAD Models/LinearActuator-100mm.SLDPRT
45.3 x 82.9 x 193.0 mm

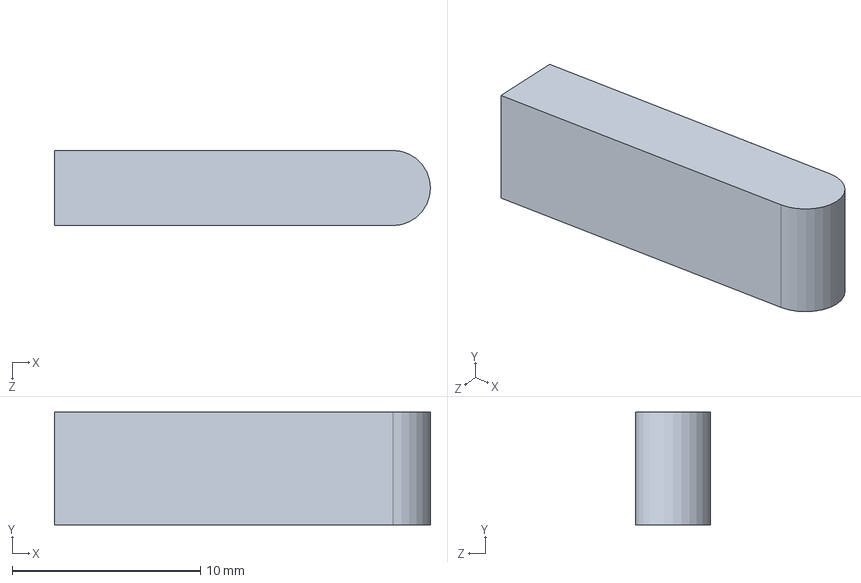
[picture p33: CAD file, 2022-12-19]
CAD Models/key.SLDPRT
20.0 x 6.00 x 4.00 mm

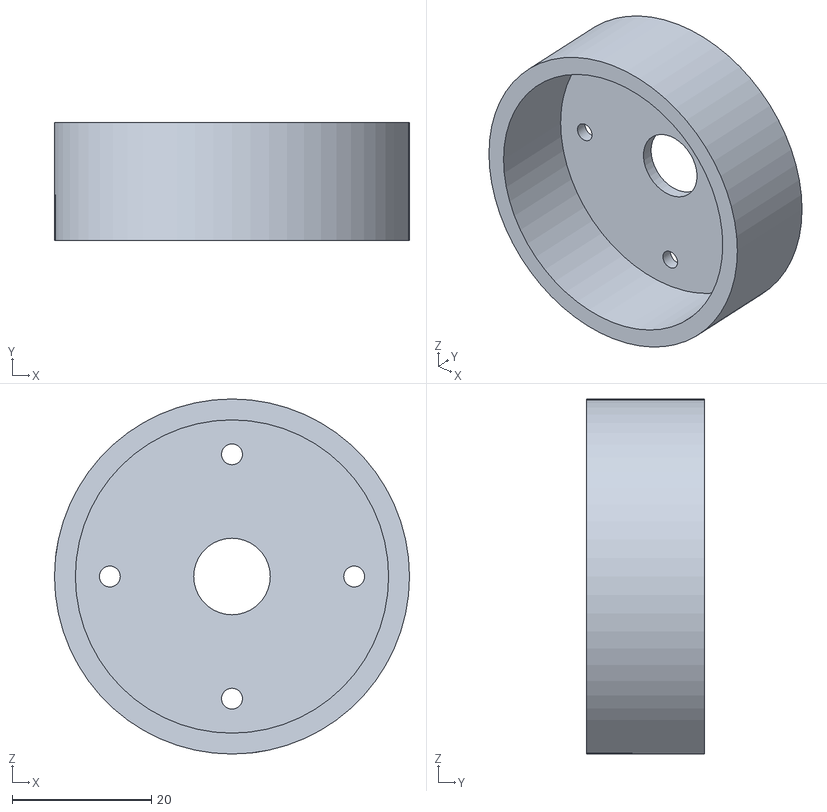
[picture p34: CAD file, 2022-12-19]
CAD Models/check.STL
51.0 x 17.0 x 51.0

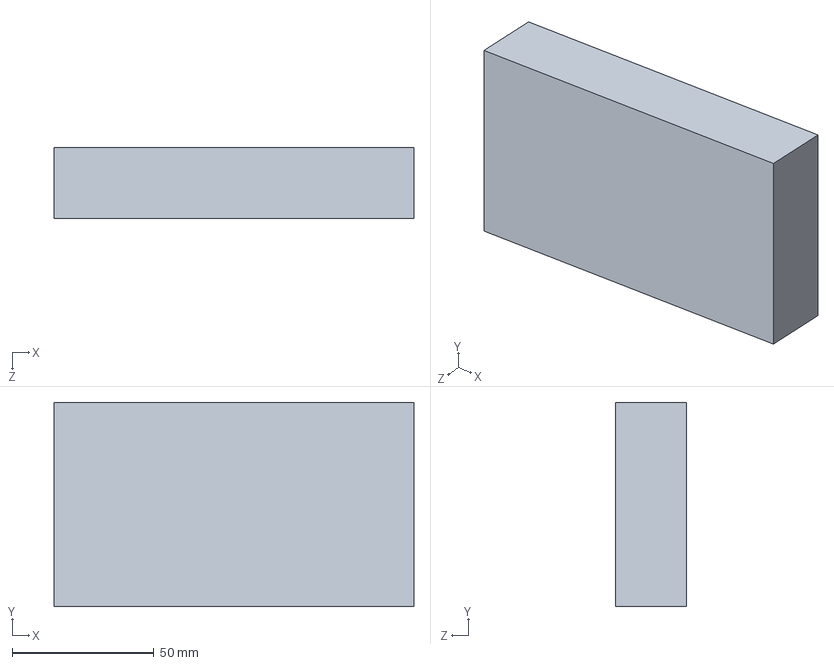
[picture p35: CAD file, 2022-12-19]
CAD Models/batteryV2.SLDPRT
126.8 x 72.0 x 25.0 mm

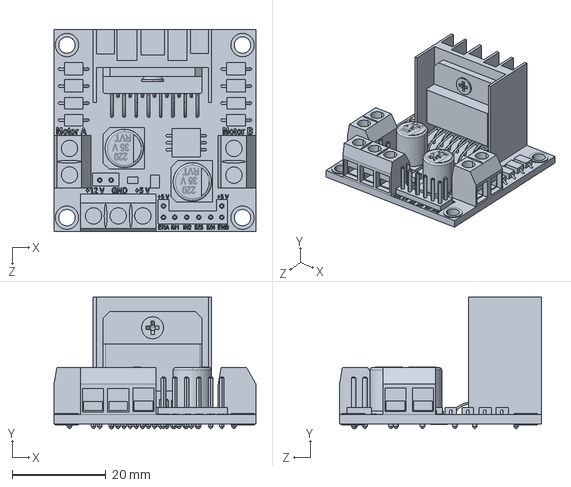
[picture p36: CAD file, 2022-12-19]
CAD Models/L298N_DriverSLDPRT.SLDPRT
43.0 x 28.0 x 43.0 mm

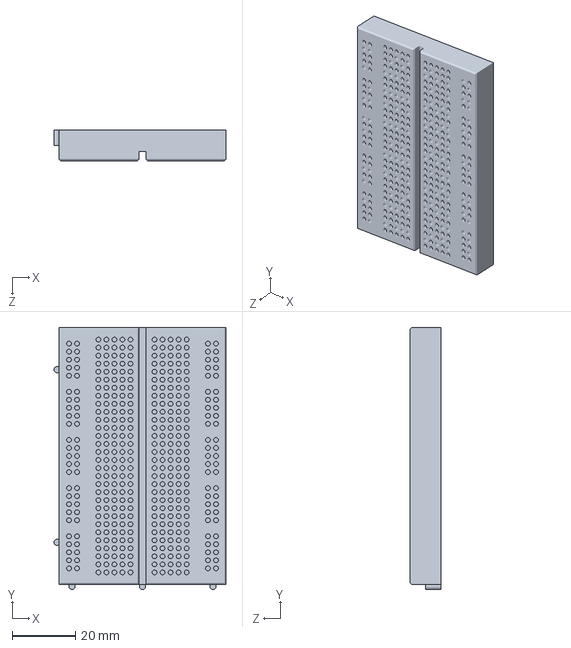
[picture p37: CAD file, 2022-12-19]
CAD Models/small_breadboard v1.SLDPRT
54.4 x 82.9 x 9.70 mm

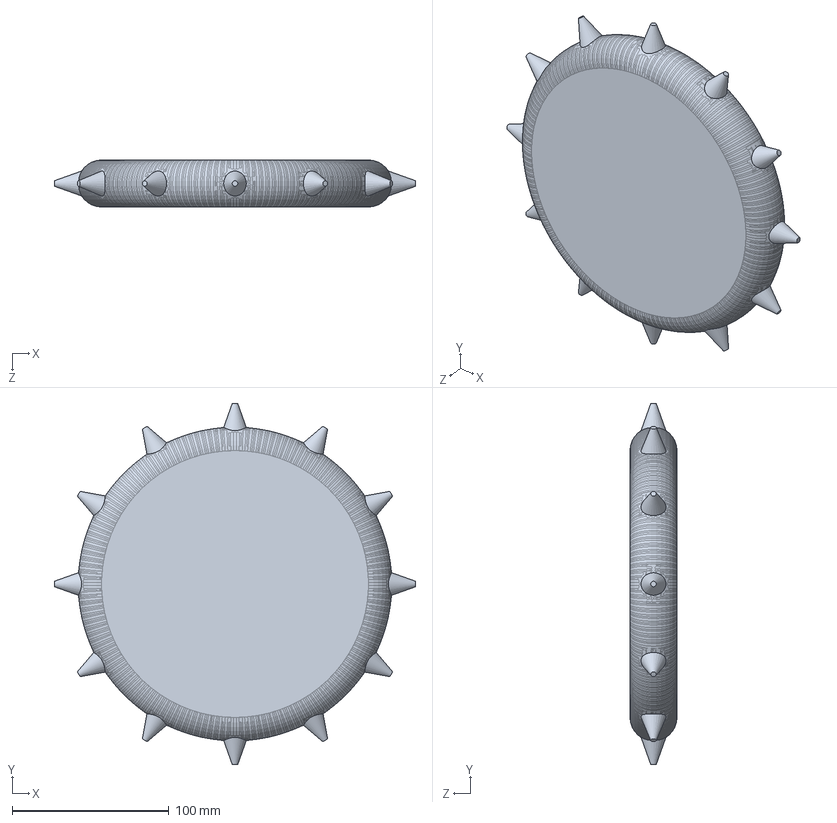
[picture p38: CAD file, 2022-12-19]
CAD Models/WheelV2.SLDPRT
230.0 x 230.0 x 30.0 mm

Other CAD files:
CAD Models/connector.SLDPRT
CAD Models/motorV2.1.SLDPRT
CAD Models/Base_3Dprint_final.STL
CAD Models/Base_3Dprint.STL
CAD Models/BO DC Motor.SLDPRT
CAD Models/Bodyv2.SLDPRT
CAD Models/Camera.SLDPRT
CAD Models/Part13.SLDPRT
CAD Models/RelayBoardSLDPRT.SLDPRT
CAD Models/WheelV2.STL
CAD Models/actuator_stroke.SLDPRT
CAD Models/motor.SLDPRT
CAD Models/motorV2.SLDPRT
CAD Models/tool_casing.SLDPRT

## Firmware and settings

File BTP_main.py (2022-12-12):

import cv2
import numpy as np
from tensorflow import keras
from dc_motor import motor_operation
#from dc_motor_2 import motor_operation
from actuator import actuator_operation
import RPi.GPIO as GPIO          
from time import sleep

# ~ ########## Setting the first motor ##########
Motor1A = 24
Motor1B = 23
Motor1E = 25
temp1_1 = 1

GPIO.setup(Motor1A,GPIO.OUT)
GPIO.setup(Motor1B,GPIO.OUT)
GPIO.setup(Motor1E,GPIO.OUT)

GPIO.output(Motor1A,GPIO.LOW)
GPIO.output(Motor1B,GPIO.LOW)
pwm1 = GPIO.PWM(Motor1E,1000)
pwm1.start(25)

# ~ ########## Setting the second motor ##########
Motor2A = 2
Motor2B = 3
Motor2E = 4
temp1_2 = 1

GPIO.setup(Motor2A,GPIO.OUT)
GPIO.setup(Motor2B,GPIO.OUT)
GPIO.setup(Motor2E,GPIO.OUT)

GPIO.output(Motor2A,GPIO.LOW)
GPIO.output(Motor2B,GPIO.LOW)
pwm2 = GPIO.PWM(Motor2E,1000)
pwm2.start(25)

# # ~ ########## Setting the third motor ##########
# Motor3A = 2
# Motor3B = 3
# Motor3E = 4
# temp1_3 = 1

# GPIO.setup(Motor3A,GPIO.OUT)
# GPIO.setup(Motor3B,GPIO.OUT)
# GPIO.setup(Motor3E,GPIO.OUT)

# GPIO.output(Motor3A,GPIO.LOW)
# GPIO.output(Motor3B,GPIO.LOW)
# pwm3 = GPIO.PWM(Motor3E,1000)
# pwm3.start(25)

# # ~ ########## Setting the second motor ##########
# Motor4A = 2
# Motor4B = 3
# Motor4E = 4
# temp1_4 = 1

# GPIO.setup(Motor4A,GPIO.OUT)
# GPIO.setup(Motor4B,GPIO.OUT)
# GPIO.setup(Motor4E,GPIO.OUT)

# GPIO.output(Motor4A,GPIO.LOW)
# GPIO.output(Motor4B,GPIO.LOW)
# pwm4 = GPIO.PWM(Motor4E,1000)
# pwm4.start(25)

####### Setting linear actuator #####
forward = 16
backward = 26

GPIO.setup(forward,GPIO.OUT)
GPIO.setup(backward,GPIO.OUT)

########## Computer Vision Model ##########
model = keras.models.load_model('BTP_CV_Resnet.h5')

img_height, img_width = 224, 224
dimensions = (img_height, img_width)

video_capture = cv2.VideoCapture(0)
count = 30
frame_width = int(video_capture.get(3))
frame_height = int(video_capture.get(4))
frame_size = (frame_width , frame_height)
writer = cv2.VideoWriter("test_video_output.avi", cv2.VideoWriter_fourcc(*('MJPG')), 10 , frame_size)


########### Loop ############
while True:  
    ret, frame = video_capture.read()  # Read in the frame
    #if (ret == True):  
    # video_capture.set(cv2.CAP_PROP_POS_FRAMES, count)   # i.e. at 30 fps, this advances one second        
    image = cv2.resize(frame, dimensions)   # resize image        
    image = cv2.cvtColor(image, cv2.COLOR_BGR2RGB)    # change color channels form bgr to rgb        
    image = (image/255).astype(np.float16)    # normalise data
    image = image.reshape(1, image.shape[0], image.shape[1], image.shape[2])

    a = model.predict(image)
    output = frame.copy()
    ##### Motor Starts ######
    x = 'r'
    motor_operation(x, Motor1A, Motor1B, pwm1, temp1_1, Motor2A, Motor2B, pwm2, temp1_2)
    #motor_operation(x, Motor1A, Motor1B, pwm1, temp1_1, Motor2A, Motor2B, pwm2, temp1_2, Motor3A, Motor3B, pwm3, temp1_3, Motor4A, Motor4B, pwm4, temp1_4)
    x = 'f'
    motor_operation(x, Motor1A, Motor1B, pwm1, temp1_1, Motor2A, Motor2B, pwm2, temp1_2)
    #motor_operation(x, Motor1A, Motor1B, pwm1, temp1_1, Motor2A, Motor2B, pwm2, temp1_2, Motor3A, Motor3B, pwm3, temp1_3, Motor4A, Motor4B, pwm4, temp1_4)


    if a<0.5:
        # print("Cotton Plant")
        text = "Cotton Plant"
        cv2.putText(output, text, (35, 50), cv2.FONT_HERSHEY_SIMPLEX, 1.25, (0, 0, 255), 5)
        x = 'm'
        motor_operation(x, Motor1A, Motor1B, pwm1, temp1_1, Motor2A, Motor2B, pwm2, temp1_2)
        #motor_operation(x, Motor1A, Motor1B, pwm1, temp1_1, Motor2A, Motor2B, pwm2, temp1_2, Motor3A, Motor3B, pwm3, temp1_3, Motor4A, Motor4B, pwm4, temp1_4)

        
    else:
        # print("Non Cotton Plant")
        text = "Non Cotton Plant"
        cv2.putText(output, text, (35, 50), cv2.FONT_HERSHEY_SIMPLEX, 1.25, (0, 0, 255), 5)
        x = 's'
        motor_operation(x, Motor1A, Motor1B, pwm1, temp1_1, Motor2A, Motor2B, pwm2, temp1_2)
        #motor_operation(x, Motor1A, Motor1B, pwm1, temp1_1, Motor2A, Motor2B, pwm2, temp1_2, Motor3A, Motor3B, pwm3, temp1_3, Motor4A, Motor4B, pwm4, temp1_4)
        actuator_operation(forward, backward)

    writer.write(output)    
    cv2.imshow('Video Output', output)   # Display the frame

    if cv2.waitKey(1) == ord('q'):
        GPIO.cleanup()
        print("GPIO Clean up")
        break

# Stop filming
video_capture.release()
writer.release()

# Close down OpenCV
cv2.destroyAllWindows()

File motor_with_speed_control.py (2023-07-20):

import RPi.GPIO as GPIO          
import time
#from camera_capture import *


GPIO.getmode(GPIO.BCM)
GPIO.setmode(GPIO.BOARD)
sleeptime=1

# ~ ########## Setting all the motor ##########
#1: Front Right, 2: Front Left, 3:Back RIght, 4: Back Left, 5: Cutting Motor 1, 6: Cutting Motor 2
Motor1A = 12
Motor1B = 13
Motor1Enable = 11
GPIO.setup(Motor1A,GPIO.OUT)
GPIO.setup(Motor1B,GPIO.OUT)
GPIO.setup(Motor1Enable,GPIO.OUT)

Motor2A = 10
Motor2B = 8
Motor2Enable = 7
GPIO.setup(Motor2A,GPIO.OUT)
GPIO.setup(Motor2B,GPIO.OUT)
GPIO.setup(Motor2Enable,GPIO.OUT)


Motor3A = 31
Motor3B = 29
Motor3Enable = 32
GPIO.setup(Motor3A,GPIO.OUT)
GPIO.setup(Motor3B,GPIO.OUT)
GPIO.setup(Motor3Enable,GPIO.OUT)


Motor4A = 36
Motor4B = 35
Motor4Enable = 33
GPIO.setup(Motor4A,GPIO.OUT)
GPIO.setup(Motor4B,GPIO.OUT)
GPIO.setup(Motor4Enable,GPIO.OUT)

Motor5A = 21
Motor5B = 22
GPIO.setup(Motor5A,GPIO.OUT)
GPIO.setup(Motor5B,GPIO.OUT)

# Motor6A = 16
# Motor6B = 18
# GPIO.setup(Motor6A,GPIO.OUT)
# GPIO.setup(Motor6B,GPIO.OUT)

# Set up PWM frequency and start PWM
pwm1 = GPIO.PWM(Motor1Enable, 100)
pwm2 = GPIO.PWM(Motor2Enable, 100)
pwm3 = GPIO.PWM(Motor3Enable, 100)
pwm4 = GPIO.PWM(Motor4Enable, 100)
pwm1.start(0)
pwm2.start(0)
pwm3.start(0)
pwm4.start(0)

############## Setting up linear actuator ############
forward_channel = 16
backward_channel = 19
GPIO.setup(forward_channel,GPIO.OUT)
GPIO.setup(backward_channel,GPIO.OUT)

############## Operation Functions ############
def forward(x, speed):
    GPIO.output(Motor1A,GPIO.HIGH)
    GPIO.output(Motor2A,GPIO.HIGH)
    GPIO.output(Motor3A,GPIO.HIGH)
    GPIO.output(Motor4A,GPIO.HIGH)
        
    pwm1.ChangeDutyCycle(speed)
    pwm2.ChangeDutyCycle(speed)
    pwm3.ChangeDutyCycle(speed)
    pwm4.ChangeDutyCycle(speed)
        

    print("Moving Forward")
    time.sleep(x)
    GPIO.output(Motor1A,GPIO.LOW)
    GPIO.output(Motor2A,GPIO.LOW)
    GPIO.output(Motor3A,GPIO.LOW)
    GPIO.output(Motor4A,GPIO.LOW)
        
    pwm1.ChangeDutyCycle(0)
    pwm2.ChangeDutyCycle(0)
    pwm3.ChangeDutyCycle(0)
    pwm4.ChangeDutyCycle(0)

########## Reverse ###########	
def reverse(x, speed):
    GPIO.output(Motor1B,GPIO.HIGH)
    GPIO.output(Motor2B,GPIO.HIGH)
    GPIO.output(Motor3B,GPIO.HIGH)
    GPIO.output(Motor4B,GPIO.HIGH)
        
    pwm1.ChangeDutyCycle(speed)
    pwm2.ChangeDutyCycle(speed)
    pwm3.ChangeDutyCycle(speed)
    pwm4.ChangeDutyCycle(speed)
        
    print("Moving Backward")
    time.sleep(x)
    GPIO.output(Motor1B,GPIO.LOW)
    GPIO.output(Motor2B,GPIO.LOW)
    GPIO.output(Motor3B,GPIO.LOW)
    GPIO.output(Motor4B,GPIO.LOW)

    pwm1.ChangeDutyCycle(0)
    pwm2.ChangeDutyCycle(0)
    pwm3.ChangeDutyCycle(0)
    pwm4.ChangeDutyCycle(0)
    
######## Left Turn #########
def left_turn(x, speed):
    GPIO.output(Motor1B,GPIO.HIGH)
    GPIO.output(Motor2A,GPIO.HIGH)
    GPIO.output(Motor3A,GPIO.HIGH)
    GPIO.output(Motor4B,GPIO.HIGH)
        
    pwm1.ChangeDutyCycle(speed)
    pwm2.ChangeDutyCycle(speed)
    pwm3.ChangeDutyCycle(speed)
    pwm4.ChangeDutyCycle(speed)

    print("Moving Left")
    time.sleep(x)
    GPIO.output(Motor1B,GPIO.LOW)
    GPIO.output(Motor2A,GPIO.LOW)
    GPIO.output(Motor3A,GPIO.LOW)
    GPIO.output(Motor4B,GPIO.LOW)

    pwm1.ChangeDutyCycle(0)
    pwm2.ChangeDutyCycle(0)
    pwm3.ChangeDutyCycle(0)
    pwm4.ChangeDutyCycle(0)

########## Right Turn ###########
def right_turn(x, speed):
    GPIO.output(Motor1A,GPIO.HIGH)    
    GPIO.output(Motor2B,GPIO.HIGH)
    GPIO.output(Motor3B,GPIO.HIGH)
    GPIO.output(Motor4A,GPIO.HIGH)

    pwm1.ChangeDutyCycle(speed)
    pwm2.ChangeDutyCycle(speed)
    pwm3.ChangeDutyCycle(speed)
    pwm4.ChangeDutyCycle(speed)

    print("Moving Right")
    time.sleep(x)
    GPIO.output(Motor1A,GPIO.LOW)
    GPIO.output(Motor2B,GPIO.LOW)
    GPIO.output(Motor3B,GPIO.LOW)
    GPIO.output(Motor4A,GPIO.LOW)

    pwm1.ChangeDutyCycle(0)
    pwm2.ChangeDutyCycle(0)
    pwm3.ChangeDutyCycle(0)
    pwm4.ChangeDutyCycle(0)

def cutting():
    GPIO.output(Motor5A, GPIO.HIGH)
    GPIO.output(Motor5B, GPIO.LOW)
    #GPIO.output(Motor6B, GPIO.HIGH)
    print("Cutting")

def stop_cutting():
    GPIO.output(Motor5A, GPIO.LOW)
    #GPIO.output(Motor6B, GPIO.LOW)
    print("Stopped Cutting")

# def right_turn_curve(x, speed):
#     GPIO.output(Motor1A,GPIO.HIGH)    
#     GPIO.output(Motor2A,GPIO.HIGH)
#     GPIO.output(Motor3A,GPIO.HIGH)
#     GPIO.output(Motor4A,GPIO.HIGH)

#     pwm1.ChangeDutyCycle(speed)
#     pwm2.ChangeDutyCycle(0)
#     pwm3.ChangeDutyCycle(0)
#     pwm4.ChangeDutyCycle(speed)

#     print("Moving Right")
#     time.sleep(x)
#     GPIO.output(Motor1B,GPIO.LOW)
#     GPIO.output(Motor2B,GPIO.LOW)
#     GPIO.output(Motor3B,GPIO.LOW)
#     GPIO.output(Motor4B,GPIO.LOW)

#     pwm1.ChangeDutyCycle(0)
#     pwm2.ChangeDutyCycle(0)
#     pwm3.ChangeDutyCycle(0)
#     pwm4.ChangeDutyCycle(0)

def actuate():
    GPIO.output(forward_channel, GPIO.HIGH)
    GPIO.output(backward_channel, GPIO.LOW)
    print("actuate")  
def dactuate():
   GPIO.output(forward_channel, GPIO.LOW)
   GPIO.output(backward_channel, GPIO.HIGH)
   print("dactuate")

while (1):
    speed = 100
    reverse(5, speed)
    # actuate()
    # time.sleep(2)
    # dactuate()
    # time.sleep(2)
    # cutting()
    # time.sleep(5)
    # stop_cutting()
    #dactuate()
    #time.sleep(5)
    #right_turn(1.5, 100)
    #time.sleep(1)
    #left_turn(1)
    #actuate()
    #time.sleep(2)
    #dactuate()
    #time.sleep(10)
    #forward(2, speed)
    #time.sleep(1)
    #right_turn(5, 100)

        # Stop motors and clean up GPIO pins
    pwm1.stop()
    pwm2.stop()
    pwm3.stop()
    pwm4.stop()

    GPIO.cleanup()
    break

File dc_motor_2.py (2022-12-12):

import RPi.GPIO as GPIO          
from time import sleep

def motor_operation(x, Motor1A, Motor1B, pwm1, temp1_1, Motor2A, Motor2B, pwm2, temp1_2, Motor3A, Motor3B, pwm3, temp1_3,
                    Motor4A, Motor4B, pwm4, temp1_4):
    if x=='r':
        print("run")
        if(temp1_1==1 and temp1_2==1 and temp1_3==1 and temp1_4==1):
            GPIO.output(Motor1A,GPIO.HIGH)
            GPIO.output(Motor1B,GPIO.LOW)
                 
            GPIO.output(Motor2A,GPIO.HIGH)
            GPIO.output(Motor2B,GPIO.LOW)
            
            GPIO.output(Motor3A,GPIO.HIGH)
            GPIO.output(Motor3B,GPIO.LOW)
            
            GPIO.output(Motor4A,GPIO.HIGH)
            GPIO.output(Motor4B,GPIO.LOW)
                 
            print("forward")
            x='z'
        else:
            GPIO.output(Motor1A,GPIO.LOW)
            GPIO.output(Motor1B,GPIO.HIGH)
                 
            GPIO.output(Motor2A,GPIO.LOW)
            GPIO.output(Motor2B,GPIO.HIGH)
            
            GPIO.output(Motor3A,GPIO.LOW)
            GPIO.output(Motor3B,GPIO.HIGH)
            
            GPIO.output(Motor4A,GPIO.LOW)
            GPIO.output(Motor4B,GPIO.HIGH)
                 
            print("backward")
            x='z'


    elif x=='s':
        print("stop")
        GPIO.output(Motor1A,GPIO.LOW)
        GPIO.output(Motor1B,GPIO.LOW)
        
        GPIO.output(Motor2A,GPIO.LOW)
        GPIO.output(Motor2B,GPIO.LOW)
        
        GPIO.output(Motor3A,GPIO.LOW)
        GPIO.output(Motor3B,GPIO.LOW)
        
        GPIO.output(Motor4A,GPIO.LOW)
        GPIO.output(Motor4B,GPIO.LOW)
        x='z'

    elif x=='f':
        print("forward")
        GPIO.output(Motor1A,GPIO.HIGH)
        GPIO.output(Motor1B,GPIO.LOW)
        
        GPIO.output(Motor2A,GPIO.HIGH)
        GPIO.output(Motor2B,GPIO.LOW)
        
        GPIO.output(Motor3A,GPIO.HIGH)
        GPIO.output(Motor3B,GPIO.LOW)
        
        GPIO.output(Motor4A,GPIO.HIGH)
        GPIO.output(Motor4B,GPIO.LOW)
        temp1_1=1
        temp1_2=1
        temp1_3=1
        temp1_4=1
        x='z'

    elif x=='b':
        print("backward")
        GPIO.output(Motor1A,GPIO.LOW)
        GPIO.output(Motor1B,GPIO.HIGH)
        
        GPIO.output(Motor2A,GPIO.LOW)
        GPIO.output(Motor2B,GPIO.HIGH)
        
        GPIO.output(Motor3A,GPIO.LOW)
        GPIO.output(Motor3B,GPIO.HIGH)
        
        GPIO.output(Motor4A,GPIO.LOW)
        GPIO.output(Motor4B,GPIO.HIGH)
        
        temp1_1=0
        temp1_2=0
        temp1_3=0
        temp1_4=0
        x='z'

    elif x=='l':
        print("low")
        pwm1.ChangeDutyCycle(25)
        pwm2.ChangeDutyCycle(25)
        pwm3.ChangeDutyCycle(25)
        pwm4.ChangeDutyCycle(25)
        x='z'

    elif x=='m':
        print("medium")
        pwm1.ChangeDutyCycle(50)
        pwm2.ChangeDutyCycle(50)
        pwm3.ChangeDutyCycle(50)
        pwm4.ChangeDutyCycle(50)
        x='z'

    elif x=='h':
        print("high")
        pwm1.ChangeDutyCycle(75)
        pwm2.ChangeDutyCycle(75)
        pwm3.ChangeDutyCycle(75)
        pwm4.ChangeDutyCycle(75)
        x='z'

    elif x=='le':
        print("Turning left")
        GPIO.output(Motor1A,GPIO.HIGH)
        GPIO.output(Motor1B,GPIO.LOW)
        
        GPIO.output(Motor2A,GPIO.LOW)
        GPIO.output(Motor2B,GPIO.HIGH)
        
        GPIO.output(Motor3A,GPIO.HIGH)
        GPIO.output(Motor3B,GPIO.LOW)
        
        GPIO.output(Motor4A,GPIO.LOW)
        GPIO.output(Motor4B,GPIO.HIGH)       
        x='z'
        
    elif x=='ri':
        print("Turning right")
        GPIO.output(Motor1A,GPIO.LOW)
        GPIO.output(Motor1B,GPIO.HIGH)
        
        GPIO.output(Motor2A,GPIO.HIGH)
        GPIO.output(Motor2B,GPIO.LOW)
        
        GPIO.output(Motor3A,GPIO.LOW)
        GPIO.output(Motor3B,GPIO.HIGH)
        
        GPIO.output(Motor4A,GPIO.HIGH)
        GPIO.output(Motor4B,GPIO.LOW)       
        x='z'       
    
    
    else:
        print("<<<  wrong data  >>>")
        print("please enter the defined data to continue.....")
